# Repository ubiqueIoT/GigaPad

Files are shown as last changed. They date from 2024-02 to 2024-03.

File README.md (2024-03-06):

# GigaPad: A Wireless Macropad based on ZMK

The firmware source repository: [ZMK Configuration](https://github.com/ubiqueIoT/zmk-config-gigapad) 

A full write up about the configuration: [Gigapad write up](https://ubiqueiot.com/posts/xiao-nrf52840-zmk)

gigapad
</br>

| Part | Quantity Used |
| --- | --- |
| [Seeed Studio XIAO nRF52840](https://amzn.to/42SCjPg) | 1 |
| [EC11 Rotary Encoder](https://amzn.to/3UNgU8d)| 1 |
| [Rotary Encoder Knob](https://amzn.to/3uBRqQz) | 1 |
| [Cherry MX Switches](https://amzn.to/3T9t7Tl) | 3 |
| [Keycaps](https://amzn.to/49hurct) | 3 |
| [Self tapping screws](https://www.mcmaster.com/catalog/130/3420/90380A344) | 4 |
| [Rubber feet](https://amzn.to/3T9w9XM) | 4 |

gigapad-inside
</br>
The battery should be soldered to the pads on the bottom of the XIAO module BEFORE mounting it to the PCB. Once the module is soldered in place on the PCB, you will **not** be able to access the battery pads again. Be careful with bare battery leads!
</br>
gigapad-schematic-screenshot
</br>
gigapad-pcb-bottom
</br>
gigapad-pcb-top
</br>
gigapad-schematic-screenshot

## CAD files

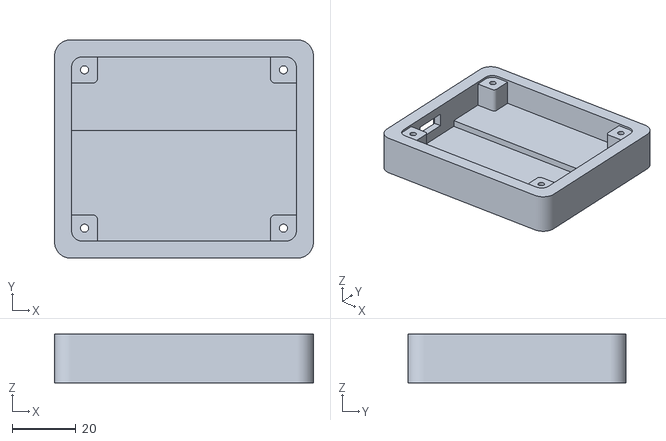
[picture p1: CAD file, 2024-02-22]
case_CAD/GigapadBase.stl
81.0 x 68.3 x 15.2

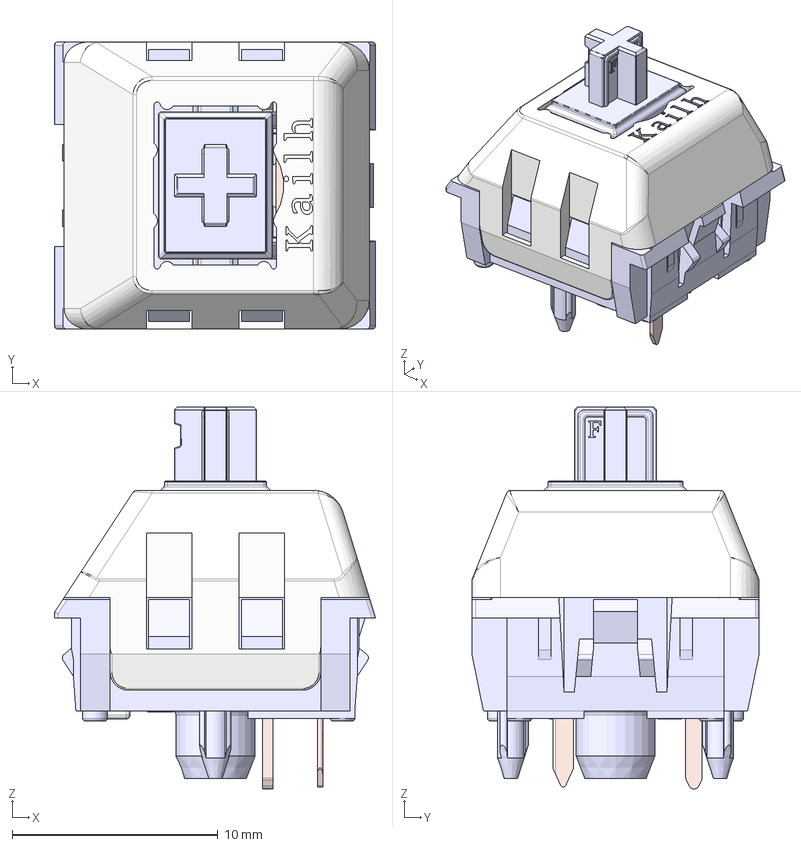
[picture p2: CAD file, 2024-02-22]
giga_pad_pcb/3D/cherry_mx.step
15.6 x 14.0 x 18.5 mm
Housing
ThickContact
SpringContact
Stem
Lid

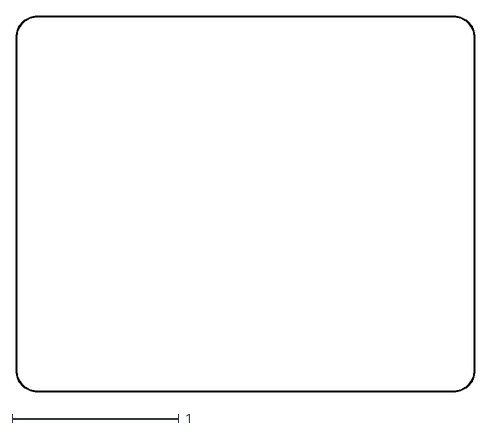
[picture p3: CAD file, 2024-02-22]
giga_pad_pcb/DXF/giga_pad-Edge_Cuts.dxf
2.75 x 2.25

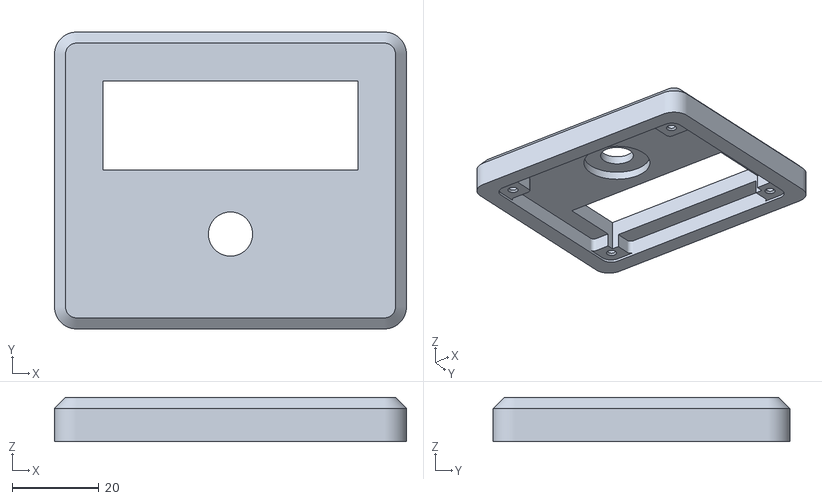
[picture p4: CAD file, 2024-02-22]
case_CAD/GigapadLid.stl
81.0 x 68.3 x 10.2

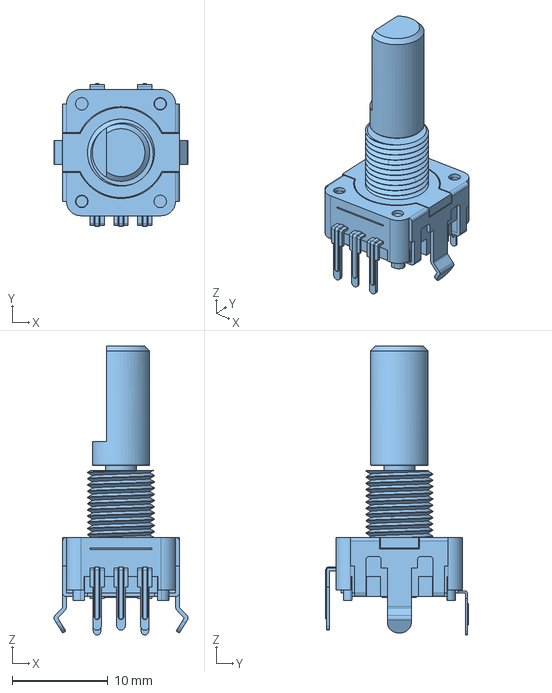
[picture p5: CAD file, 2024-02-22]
giga_pad_pcb/3D/Bourns_-_PEC11R-4220F-S0024.step
14.0 x 14.9 x 30.2 mm

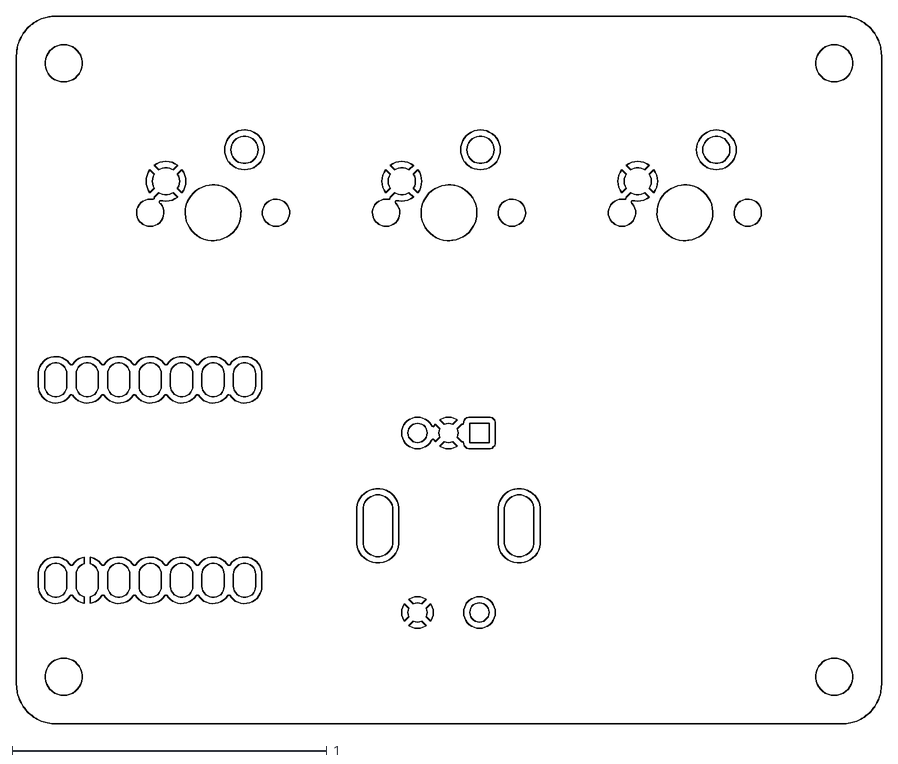
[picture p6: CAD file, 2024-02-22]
giga_pad_pcb/DXF/giga_pad-F_Cu.dxf
2.75 x 2.25

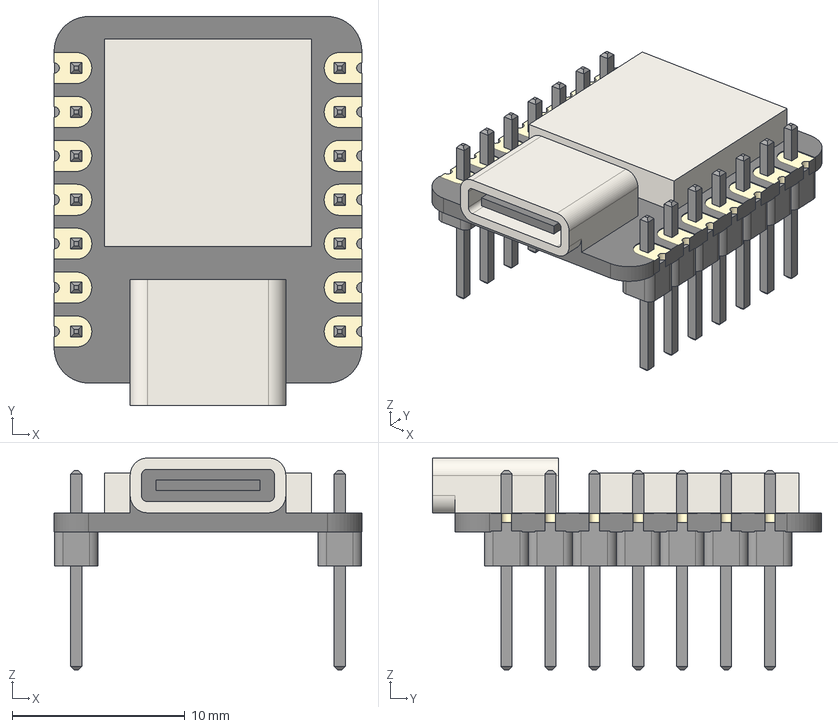
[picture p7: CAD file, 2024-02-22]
giga_pad_pcb/3D/nRFSeeedXaio.step
17.8 x 22.5 x 12.3 mm
Pino003 x 2
Pino001 x 2
Base001 x 2
Base003 x 2
Pino006 x 2
Base004 x 2
Pino002 x 2
Seeeduino Xiao v2
Pino005 x 2
Base005 x 2
Base006 x 2
Base002 x 2
Pino x 2
Base x 2
Pino004 x 2

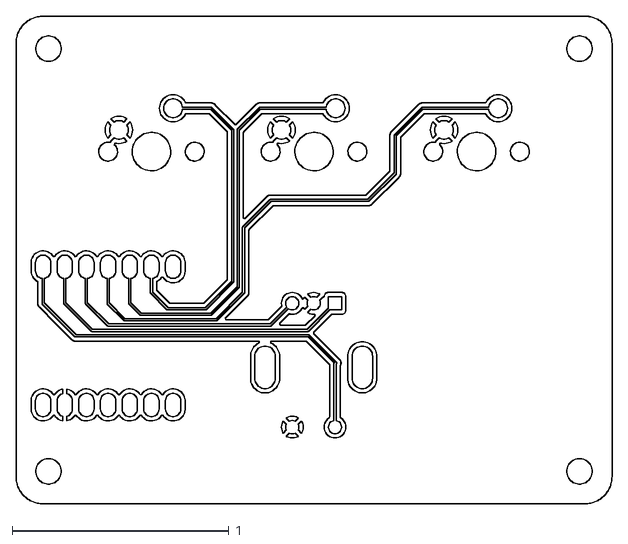
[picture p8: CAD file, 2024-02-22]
giga_pad_pcb/DXF/giga_pad-B_Cu.dxf
2.75 x 2.25

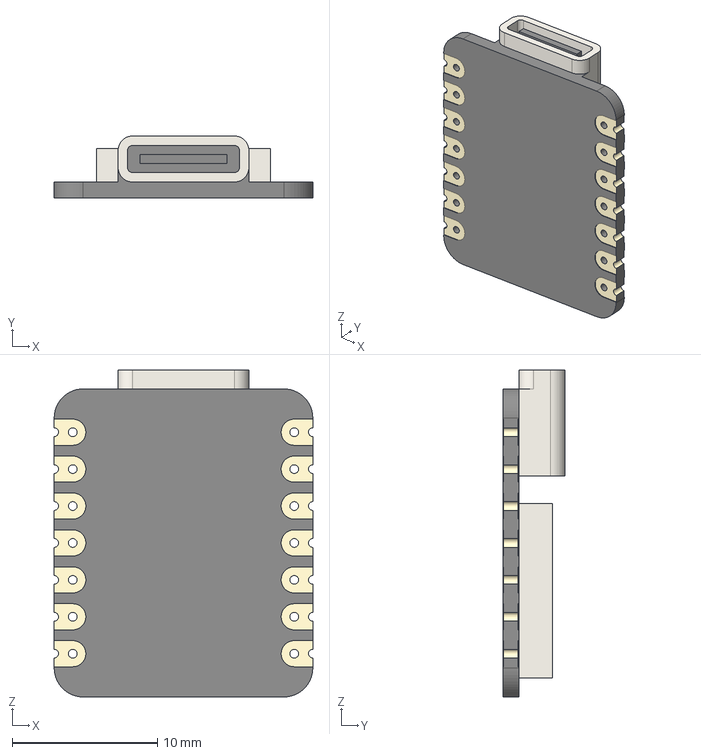
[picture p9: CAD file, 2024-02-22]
giga_pad_pcb/3D/Seeeduino_Xiao.step
17.8 x 4.27 x 22.5 mm

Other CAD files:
giga_pad_pcb/DXF/giga_pad-B_Mask.dxf
giga_pad_pcb/DXF/giga_pad-B_Paste.dxf
giga_pad_pcb/DXF/giga_pad-B_Silkscreen.dxf
giga_pad_pcb/DXF/giga_pad-F_Mask.dxf
giga_pad_pcb/DXF/giga_pad-F_Paste.dxf
giga_pad_pcb/DXF/giga_pad-F_Silkscreen.dxf

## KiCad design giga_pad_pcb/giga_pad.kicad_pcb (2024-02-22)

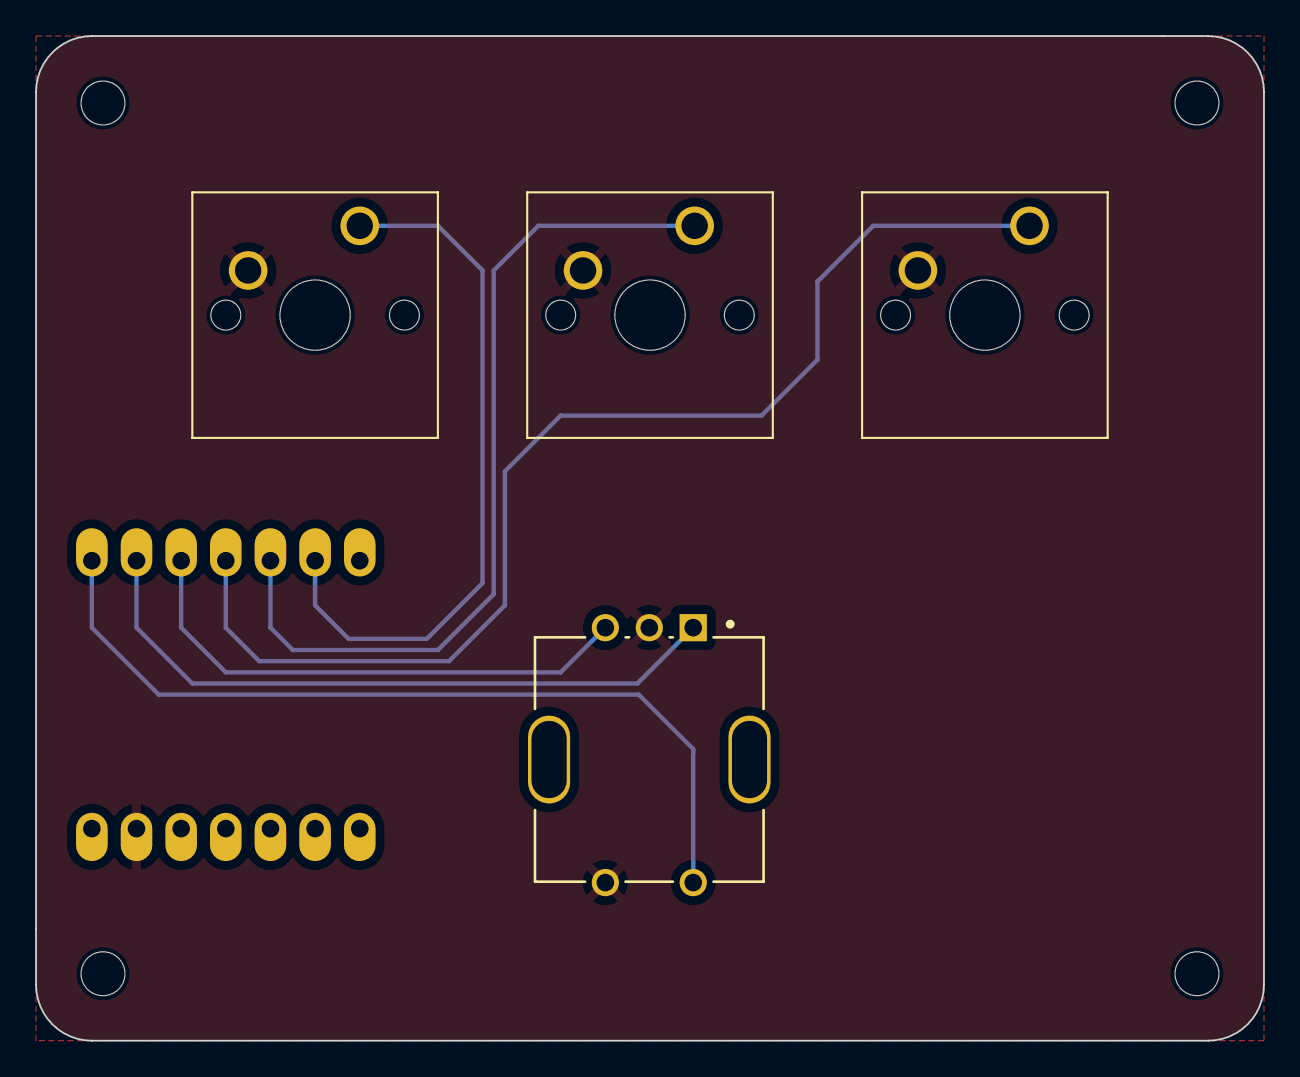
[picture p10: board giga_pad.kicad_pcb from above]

Board: 2 copper layers, 69.8 x 57.2 mm, 9 parts (1 on the bottom side), 7 nets.

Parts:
H1, H2, H3, H4: MountingHole; MountingHole_2.5mm
SW1: RotaryEncoder_Switch; Bourns-PEC11R-4220F-S0024-0-0-0
SW2, SW3, SW4: SW_Push; SW_Cherry_MX_1.00u_PCB
U1: SeeeduinoXIAO; xiao-tht

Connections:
GND: SW1.2, SW1.C, SW2.2, SW3.2, SW4.2, U1.13 (GND)
ROT_A: SW1.A, U1.2 (PA4_A1_D1)
ROT_B: SW1.B, U1.3 (PA10_A2_D2)
ROT_SW: SW1.1, U1.1 (PA02_A0_D0)
SW_2: SW2.1, U1.4 (PA11_A3_D3)
SW_3: SW3.1, U1.5 (PA8_A4_D4_SDA)
SW_4: SW4.1, U1.6 (PA9_A5_D5_SCL)
